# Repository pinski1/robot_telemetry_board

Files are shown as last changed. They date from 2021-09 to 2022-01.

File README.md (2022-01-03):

# Robot Telemetry Board

[Telemetry firmware available here](https://github.com/mjg59/robot_telemetry_viewer)

board files in ./board

schematic in ./output

See the "bridge" directory for code to use this board as an opto-isolated
USB serial bridge.

See the "analysis" directory for code used to analyze the resulting logs.

You can [buy the PCB directly from
OSHPark](https://oshpark.com/shared_projects/APZSUiwL) if you'd like to use it.

If you use the board, it would be super cool of you to give us credit.

The BOM is in BOM.csv

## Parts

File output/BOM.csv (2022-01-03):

Part |  |  | Part number | Board location | Number of parts per board | number of parts for 7 boards | datasheet | ordered
optocouplers | Vishay VOM452T 1MBps optocoupler |  | https://www.mouser.com/ProductDetail/Vishay-Semiconductors/VOM452T | U6, U7, U2, U4, U8, U9, U3, U5 | 8 | 56 |  | x
radio |  |  |  |  | 1 | 7
accelerometer | EVAL-ADXL372Z |  |  | U1 | 1 | 7
input resistor | 95 ohms | "0603" | https://www.mouser.com/ProductDetail/YAGEO/RC0603JR-7W100RL?qs=tggtontpCXNb6PZs9ghEpg%3D%3D | R9, R10, R1, R3, R11, R12, R2, R4 | 8 | 56 |  | x
output resistor | 1.9k | "0603" | https://www.mouser.com/ProductDetail/755-SDR03EZPJ182 | R13, R14, R5, R7, R15, R16, R6, R8 | 8 | 56 |  | x
power led resistor | 840 ohms | "0603" | https://www.mouser.com/ProductDetail/Panasonic/ERJ-PA3F8660V?qs=BzJM0faLVqUafluXBRs%2FoA%3D%3D | R17 | 1 | 7 |  | x
output cap | 0.1 uF | "0603" | https://www.mouser.com/ProductDetail/Taiyo-Yuden/LMK107B7224KA-T?qs=PzICbMaShUeYy583aq%2F9Ug%3D%3D | C5, C6, C1, C3, C7, C8, C2, C4 | 8 | 56 |  | x
2-pin conector | Connector_JST:JST_PH_B2B-PH-K_1x02_P2.00mm_Vertical |  |  | POWER1, J2 | 2 | 14
4-pin connector | Connector_JST:JST_PH_B4B-PH-K_1x04_P2.00mm_Vertical |  |  | J5, J1, J10, J3, J6 | 5 | 35
power LED |  | "0603" | https://www.mouser.com/ProductDetail/859-LTST-C194TBKT | D1 | 1 | 7
5V TVS |  |  | https://www.mouser.com/ProductDetail/Diodes-Incorporated/SMAJ50AQ-13-F?qs=17u8i%2FzlE8%2FlC4rBSQmAww%3D%3D | D3 | 1 | 7
reverse voltage protection diode |  | "0603" | https://www.mouser.com/ProductDetail/Comchip-Technology/CDBU0340?qs=2qJf6qQ4IOJBlNKweYgMfw%3D%3D | D2 | 1 | 7
0603 ptc |  |  | https://www.mouser.com/ProductDetail/Littelfuse/0603L020YR?qs=PalBzRKzfnvE7OEyWdBD6A%3D%3D | F1 | 1 | 7 | https://www.mouser.com/datasheet/2/240/Littelfuse_PTC_0603L_Datasheet_pdf-596523.pdf
0.1" pin strip | 5 |  | https://www.mouser.com/ProductDetail/Preci-dip/350-10-105-00-006101?qs=6AoMy99Q1XczKcQHGMMCKQ%3D%3D | For EVAL-ADXL372Z | 2 | 14
0.1" pin strip | 24 |  | https://www.mouser.com/ProductDetail/Molex/90120-0784?qs=PvP5v7EimsngJkBSR8%2FBJg%3D%3D | For Teensy 4.1 | 2 | 14
Teensy 4.1

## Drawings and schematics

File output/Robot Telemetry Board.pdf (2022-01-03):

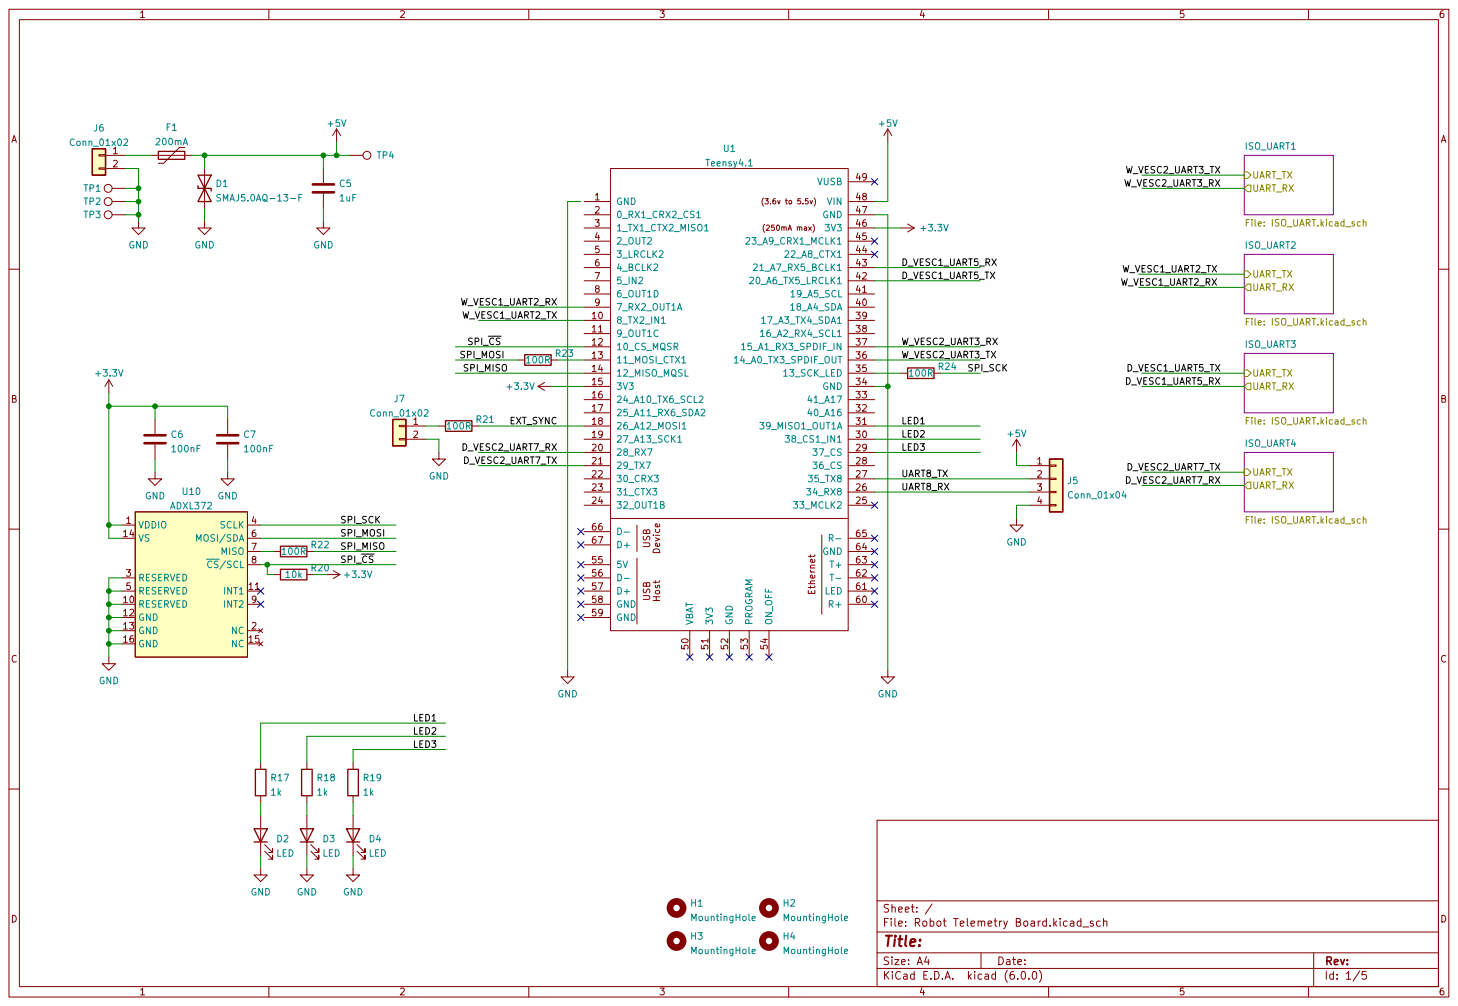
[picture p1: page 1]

File: Robot Telemetry Board.kicad_sch Sheet: /
Id: 1/5 Title:

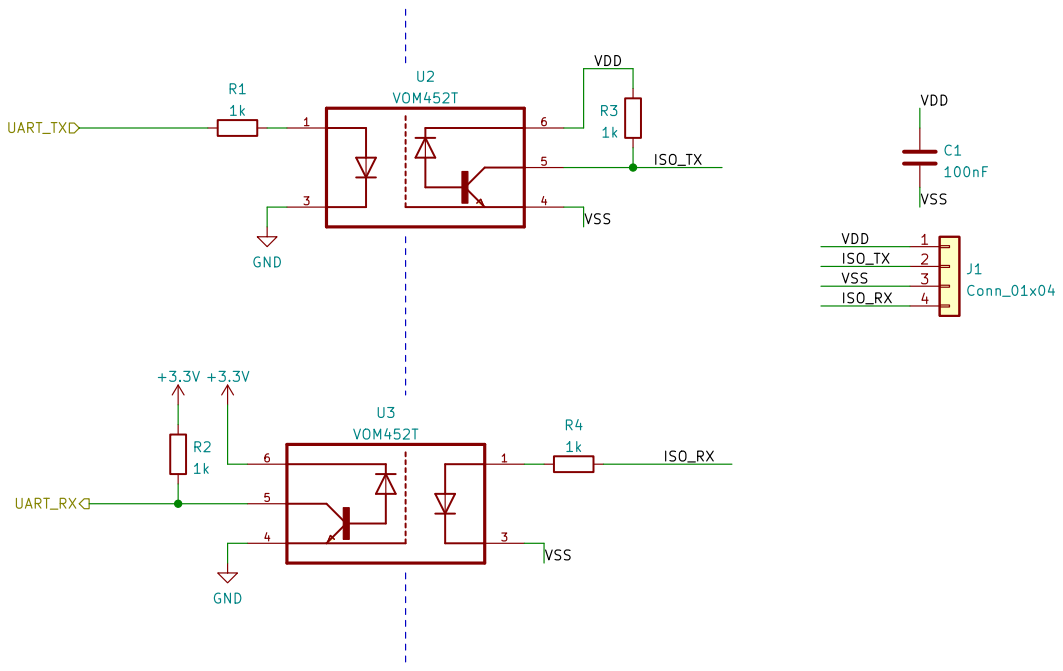
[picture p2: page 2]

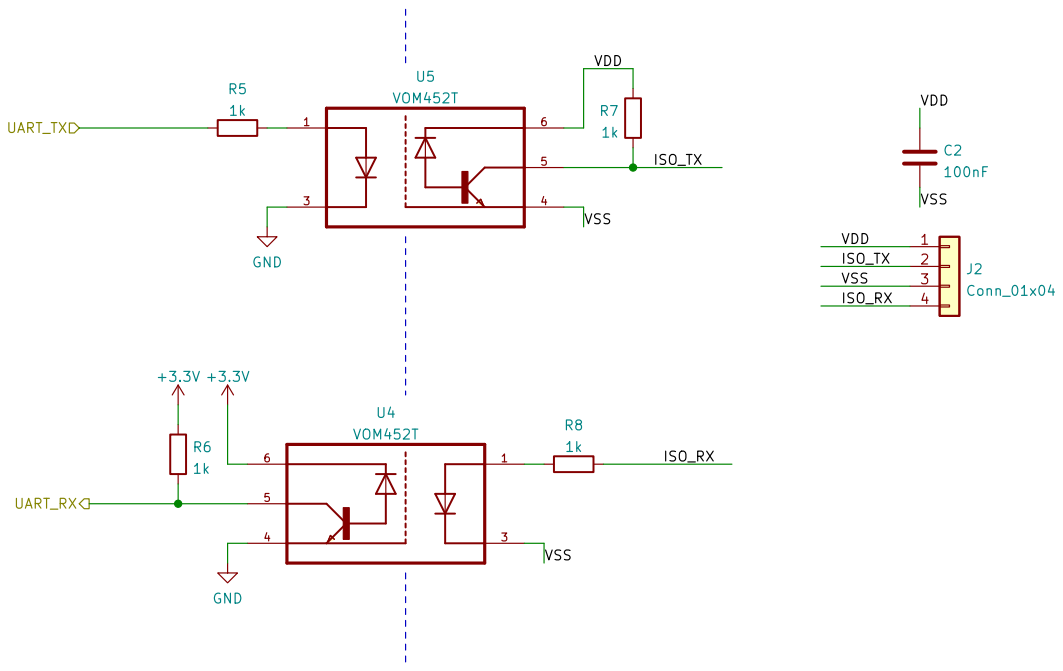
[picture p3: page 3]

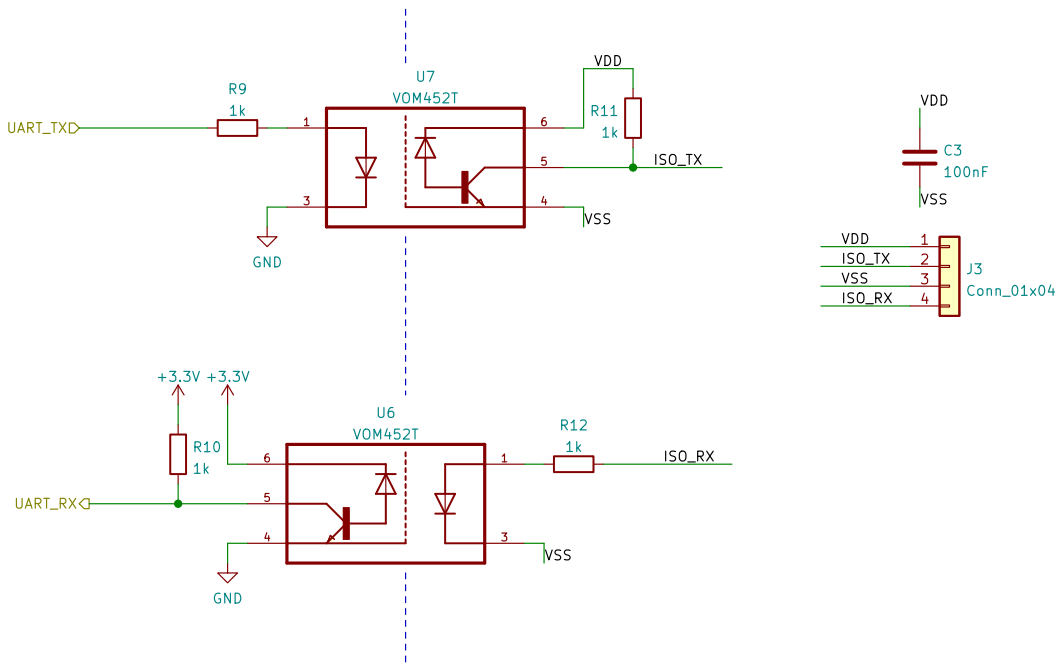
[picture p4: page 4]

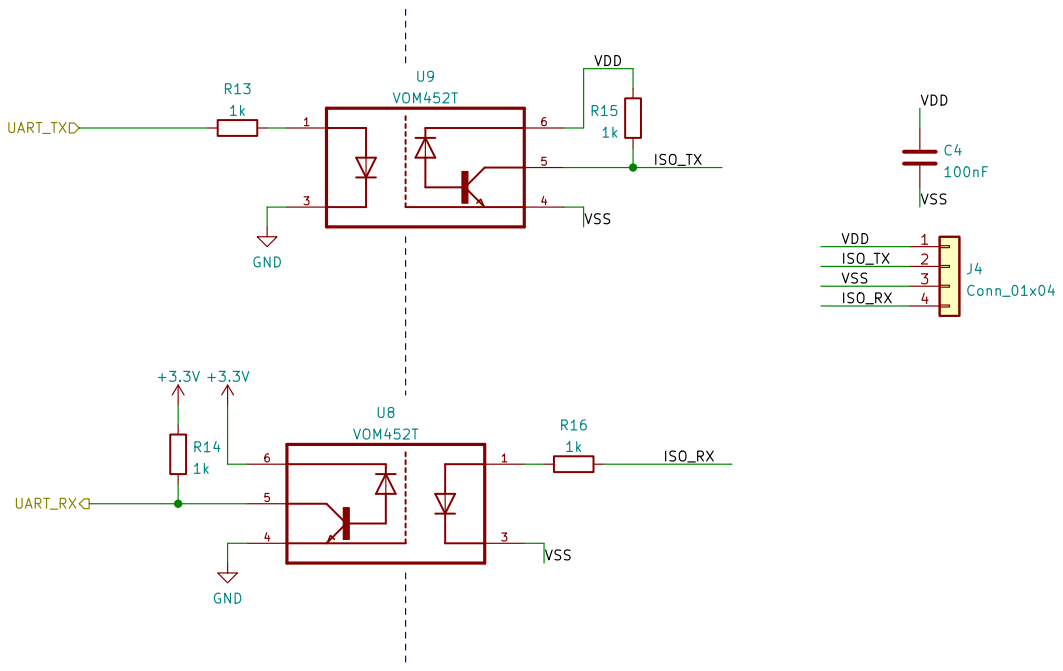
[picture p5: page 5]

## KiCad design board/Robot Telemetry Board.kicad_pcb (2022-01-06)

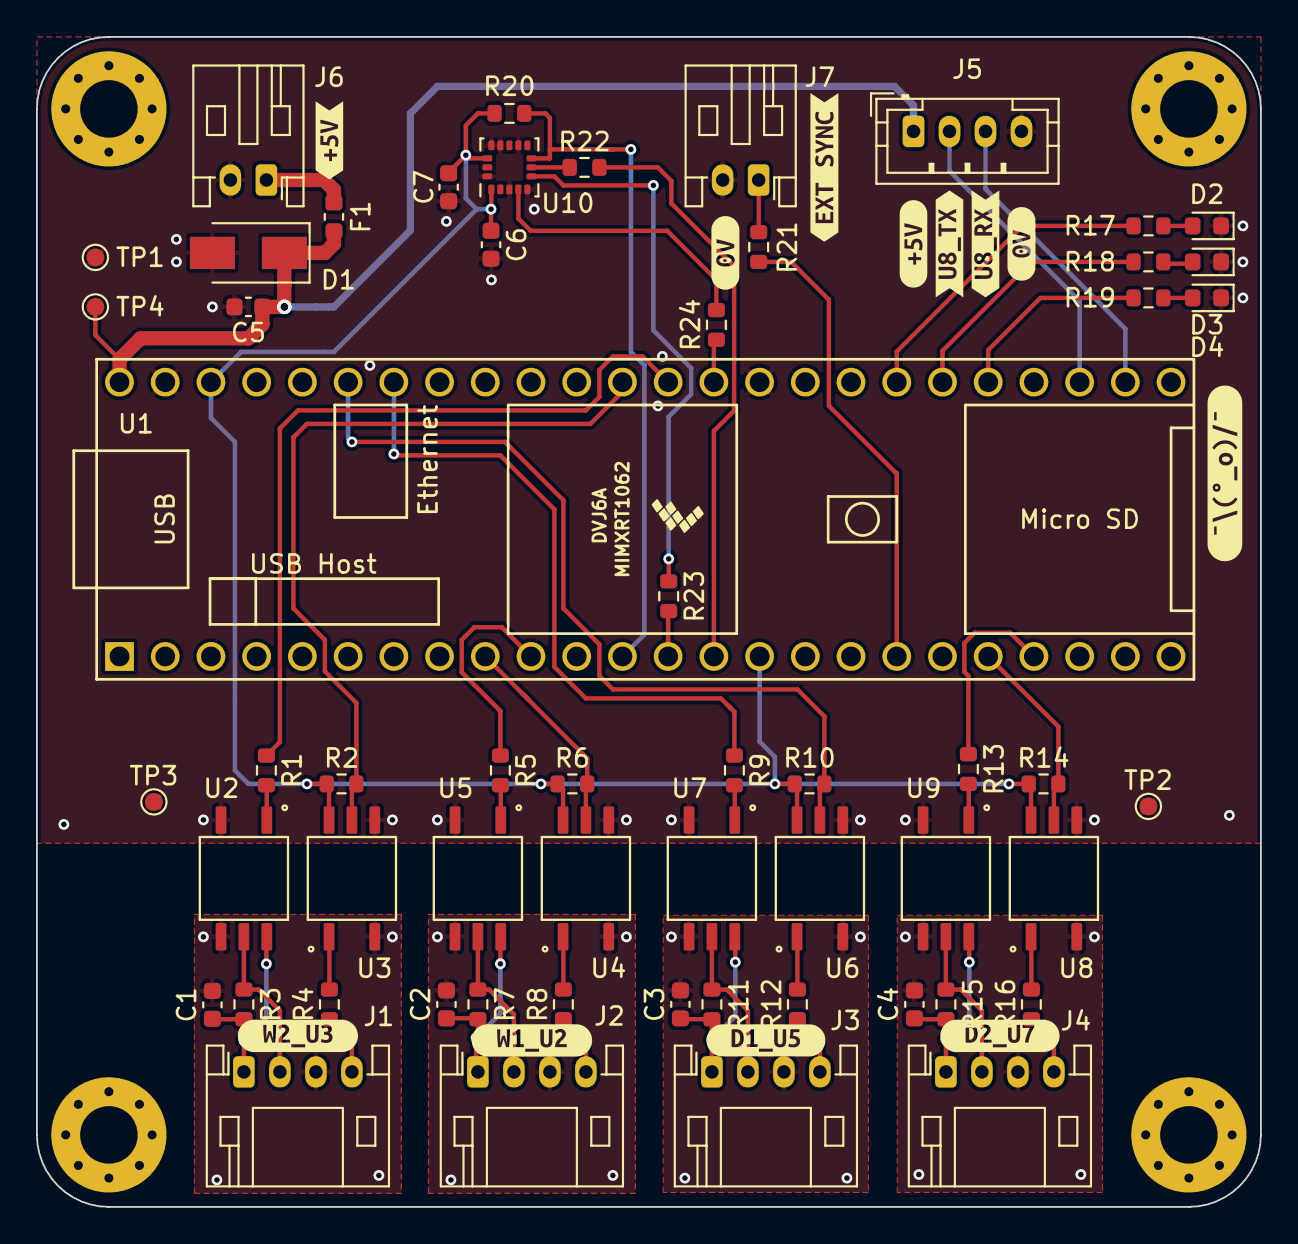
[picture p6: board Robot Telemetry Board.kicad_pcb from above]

Board: 2 copper layers, 68.0 x 65.0 mm, 73 parts (0 on the bottom side), 53 nets.

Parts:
C1, C2, C3, C4, C6, C7: 100nF; C_0603_1608Metric
C5: 1uF; C_0603_1608Metric
D1: SMAJ5.0AQ-13-F; D_SMA
D2, D3, D4: LED; LED_0603_1608Metric
F1: 200mA; Fuse_0603_1608Metric
H1, H2, H3, H4: MountingHole; MountingHole_3.2mm_M3_Pad_Via
J1, J2, J3, J4: Conn_01x04; JST_PH_S4B-PH-K_1x04_P2.00mm_Horizontal
J5: Conn_01x04; JST_PH_B4B-PH-K_1x04_P2.00mm_Vertical
J6, J7: Conn_01x02; JST_PH_S2B-PH-K_1x02_P2.00mm_Horizontal
R1, R2, R3, R4, R5, R6, R7, R8, R9, R10, R11, R12, R13, R14, R15, R16, R17, R18, R19: 1k; R_0603_1608Metric
R20: 10k; R_0603_1608Metric
R21, R22, R23, R24: 100R; R_0603_1608Metric
TP1, TP2, TP3, TP4: TestPoint; TestPoint_Pad_D1.0mm
U1: Teensy4.1; Teensy41_DIP
U2, U3, U4, U5, U6, U7, U8, U9: VOM452T; SOIC127P700X230-5N
U10: ADXL372; LGA-16_3x3mm_P0.5mm_LayoutBorder3x5y
kibuzzard-61D772F0: G***; kibuzzard-61D772F0
kibuzzard-61D773E1: G***; kibuzzard-61D773E1
kibuzzard-61D773F7: G***; kibuzzard-61D773F7
kibuzzard-61D7731E: G***; kibuzzard-61D7731E
kibuzzard-61D7737B, kibuzzard-61D7737B#2: G***; kibuzzard-61D7737B
kibuzzard-61D7742A: G***; kibuzzard-61D7742A
kibuzzard-61D7757F: G***; kibuzzard-61D7757F
kibuzzard-61D77360: G***; kibuzzard-61D77360
kibuzzard-61D77558: G***; kibuzzard-61D77558
kibuzzard-61D77572: G***; kibuzzard-61D77572
kibuzzard-61D77595: G***; kibuzzard-61D77595

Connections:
+3V3: C6.1, C7.1, R2.1, R6.1, R10.1, R14.1, R20.2, U1.15 (3V3), U1.46 (3V3), U3.6, U4.6, U6.6, U8.6, U10.1 (VDDIO), U10.14 (VS)
+5V: C5.1, D1.1 (A1), F1.1, J5.1, TP4.1, U1.48 (VIN)
/D_VESC1_UART5_RX: R10.2, U1.43 (21_A7_RX5_BCLK1), U6.5
/D_VESC1_UART5_TX: R9.1, U1.42 (20_A6_TX5_LRCLK1)
/D_VESC2_UART7_RX: R14.2, U1.20 (28_RX7), U8.5
/D_VESC2_UART7_TX: R13.1, U1.21 (29_TX7)
/EXT_SYNC: R21.2, U1.18 (26_A12_MOSI1)
/ISO_UART1/ISO_RX: J1.4, R4.1
/ISO_UART1/ISO_TX: J1.2, R3.2, U2.5
/ISO_UART1/VDD: C1.1, J1.1, R3.1, U2.6
/ISO_UART1/VSS: C1.2, J1.3, U2.4, U3.3
/ISO_UART2/ISO_RX: J2.4, R8.1
/ISO_UART2/ISO_TX: J2.2, R7.2, U5.5
/ISO_UART2/VDD: C2.1, J2.1, R7.1, U5.6
/ISO_UART2/VSS: C2.2, J2.3, U4.3, U5.4
/ISO_UART3/ISO_RX: J3.4, R12.1
/ISO_UART3/ISO_TX: J3.2, R11.2, U7.5
/ISO_UART3/VDD: C3.1, J3.1, R11.1, U7.6
/ISO_UART3/VSS: C3.2, J3.3, U6.3, U7.4
/ISO_UART4/ISO_RX: J4.4, R16.1
/ISO_UART4/ISO_TX: J4.2, R15.2, U9.5
/ISO_UART4/VDD: C4.1, J4.1, R15.1, U9.6
/ISO_UART4/VSS: C4.2, J4.3, U8.3, U9.4
/LED1: R17.1, U1.31 (39_MISO1_OUT1A)
/LED2: R18.1, U1.30 (38_CS1_IN1)
/LED3: R19.1, U1.29 (37_CS)
/SPI_MISO: R22.2, U1.14 (12_MISO_MQSL)
/SPI_MOSI: R23.1, U10.6 (MOSI/SDA)
/SPI_SCK: R24.2, U10.4 (SCLK)
/SPI_~CS: R20.1, U1.12 (10_CS_MQSR), U10.8 (~CS/SCL)
/UART8_RX: J5.3, U1.26 (34_RX8)
/UART8_TX: J5.2, U1.27 (35_TX8)
/W_VESC1_UART2_RX: R6.2, U1.9 (7_RX2_OUT1A), U4.5
/W_VESC1_UART2_TX: R5.1, U1.10 (8_TX2_IN1)
/W_VESC2_UART3_RX: R2.2, U1.37 (15_A1_RX3_SPDIF_IN), U3.5
/W_VESC2_UART3_TX: R1.1, U1.36 (14_A0_TX3_SPDIF_OUT)
GND: C5.2, C6.2, C7.2, D1.2 (A2), D2.1 (K), D3.1 (K), D4.1 (K), J5.4, J6.2, J7.2, TP1.1, TP2.1, TP3.1, U1.34 (GND), U1.47 (GND), U2.3, U3.4, U4.4, U5.3, U6.4, U7.3, U8.4, U9.3, U10.3 (RESERVED), U10.5 (RESERVED), U10.10 (RESERVED), U10.12 (GND), U10.13 (GND), U10.16 (GND)
unnamed: D2.2 (A), R17.2
unnamed: D3.2 (A), R18.2
unnamed: D4.2 (A), R19.2
unnamed: F1.2, J6.1
unnamed: J7.1, R21.1
unnamed: R5.2, U5.1
unnamed: R8.2, U4.1
unnamed: R9.2, U7.1
unnamed: R12.2, U6.1
unnamed: R13.2, U9.1
unnamed: R16.2, U8.1
unnamed: R22.1, U10.7 (MISO)
unnamed: R23.2, U1.13 (11_MOSI_CTX1)
unnamed: R24.1, U1.35 (13_SCK_LED)
unnamed: R1.2, U2.1
unnamed: R4.2, U3.1

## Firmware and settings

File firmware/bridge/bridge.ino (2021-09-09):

//#define TESTING 1
#ifdef TESTING
#define SERIAL_FORMAT SERIAL_8N1
#else
#define SERIAL_FORMAT SERIAL_8N1_RXINV_TXINV
#endif
#define SERIAL_BUFFER_SIZE 256

HardwareSerial *serial;

struct vescData {
  char vescnum;
  HardwareSerial *serial;
};

struct vescData vescs[4] =
  {{0, &Serial2},
   {1, &Serial3},
   {2, &Serial5},
   {3, &Serial7}};

void setup() {
  // Debug serial is always the default
  Serial.begin(115200);
  // VESC serials depend on whether we need inverted signals or not
  Serial2.begin(115200, SERIAL_FORMAT);
  Serial3.begin(115200, SERIAL_FORMAT);
  Serial5.begin(115200, SERIAL_FORMAT);
  Serial7.begin(115200, SERIAL_FORMAT);
  delay(5000);
  Serial.print("Serial intialized\n");
}

void loop() {
  /* Variables that need to persist across iterations of the main loop */
  static int vescbridge = 0;
  if (vescbridge < 0 || vescbridge > 3) {
    Serial.print("Vescbridge value out of range. Unknown value:");
    Serial.print(vescbridge);
    delay(5000);
  }

  while (vescs[vescbridge].serial->available()) {
    Serial.write(vescs[vescbridge].serial->read());
  }
  while (Serial.available()) {
    vescs[vescbridge].serial->write(Serial.read());
  }
}

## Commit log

2021-09-09 Add design files
    [BOM.csv, Teensy_4.0_Assembly.STEP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]
2021-09-15 Add analysis script
    [test-spin-accel.csv, test-spin-weapons.csv]
2022-01-03 applying the shrinkray!
    [BOM.csv, ISO_UART.kicad_sch, Robot Telemetry Board.kicad_pcb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]
2022-01-03 Completing the top half
    [ISO_UART.kicad_sch, Robot Telemetry Board.kicad_pcb, Robot Telemetry Board.kicad_sch]
2022-01-03 updating optocouplers
    [ISO_UART.kicad_sch, Robot Telemetry Board.kicad_pcb, Robot Telemetry Board.kicad_sch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]
2022-01-03 Updating pdf
    [ISO_UART.kicad_sch, Robot Telemetry Board.kicad_sch]
2022-01-05 Adding LCSC part numbers
    [ISO_UART.kicad_sch, Robot Telemetry Board.kicad_pcb, Robot Telemetry Board.kicad_sch]
2022-01-06 Adding some labels
    [Robot Telemetry Board.kicad_pcb]
